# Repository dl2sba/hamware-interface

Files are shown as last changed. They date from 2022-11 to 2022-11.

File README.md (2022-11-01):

# General
A small interface board for the HAMWARE controllers AT-502, AT-515 and AT-651. This interface boards supports RS232 and CI-V communications and can be directly mounted into the controller chassis.

It is supported by my alternative HAMWARE firmware https://dl2sba.com/index.php/funk/hamware.
Some images can be found in the **images** folder.

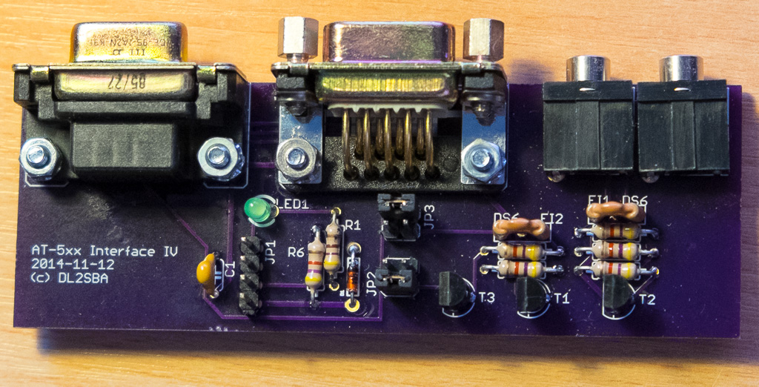
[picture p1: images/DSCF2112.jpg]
Board top

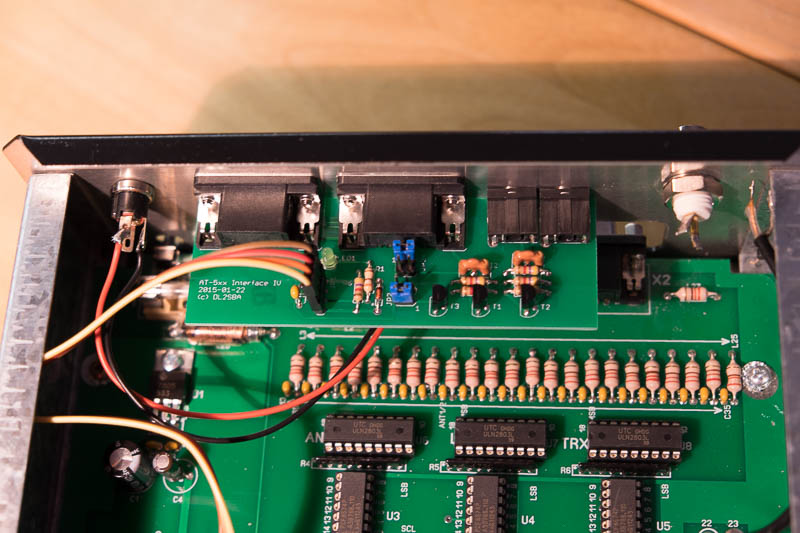
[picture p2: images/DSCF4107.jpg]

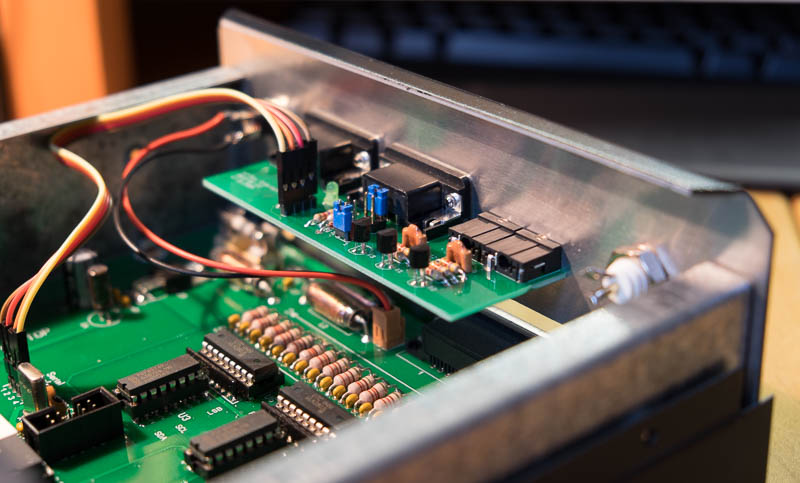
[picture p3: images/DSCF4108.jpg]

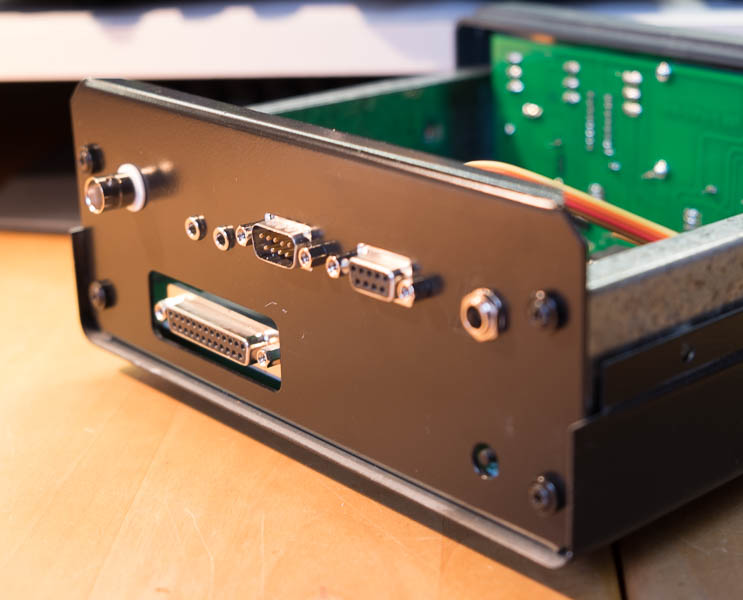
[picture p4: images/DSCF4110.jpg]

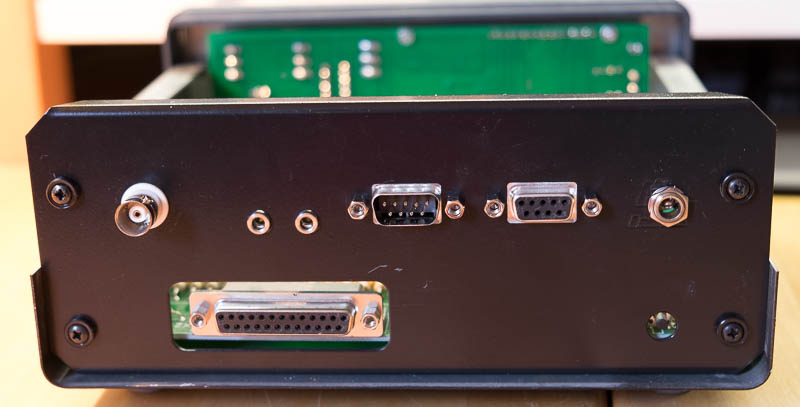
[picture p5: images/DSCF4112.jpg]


# Manual
A detailled manual can be found in **HamwareInterface_EN.pdf**

# Backpanel 
A drawing for the backpanel cutouts can be found in **Backplane.dxf**. Please verify that the cutouts matches you board / components.

# PCB production files
All relevant files can be found in the **production files** files folder. ZIP the complete folder and upload it on the webpage of one of the main PCB manufacturer.

Please verify with your PCB manufacturer that the boards satisfy your requirements.

# Parts
A public parts list for **10** boards can be found at REICHELT **https://www.reichelt.de/my/1027630**
Please adjust the part count to your requirements!

# License
The files provided here under this license **https://creativecommons.org/licenses/by-nc-nd/4.0/**
(C) Dietmar Krause, DL2SBA 2022

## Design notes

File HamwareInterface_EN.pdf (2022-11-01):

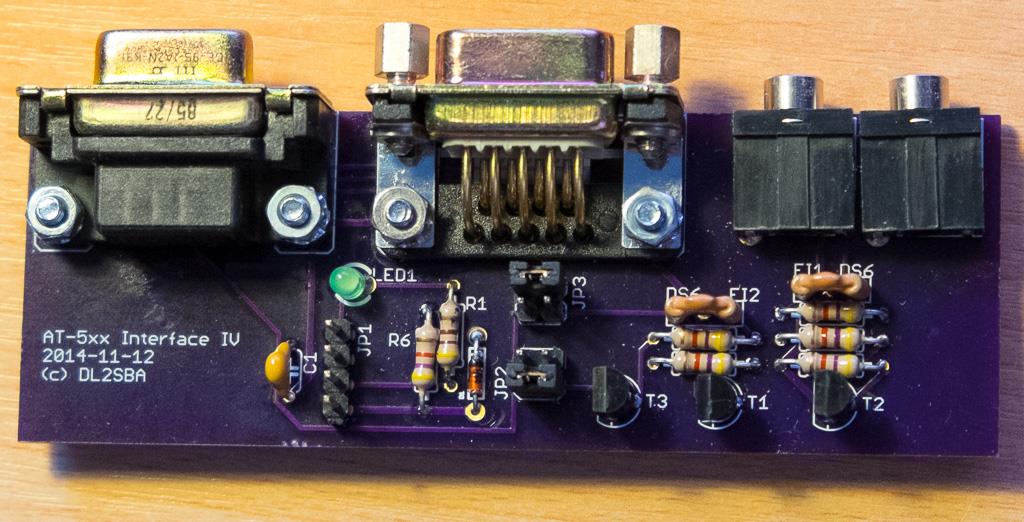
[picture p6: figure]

# Serial transceiver interface for hamware tuners

Dietmar Krause

DL2SBA

Hindenburgstraße 29

D-70794 Filderstadt

http://creativecommons.org/licenses/by-nc-nd/3.0 | Saturday, 10. February 2018

Serial transceiver interface for hamware tuners – PCB version 2015-01-22

© Dietmar Krause, DL2SBA 2018 | 2 / 9

### Content

### Change history

Version | Date | Who | Changes
1.0 | 30. December 2014 DL2SBA | Initial version
1.1 | 14. April 2017 | DL2SBA | Updated
1.2 | 4. February 2018 | DL2SBA | Updated
1.3 | 10. February 2018 | DL2SBA | Added images for new PCB layout

Remark: Any changes that you make on the control unit of the AT-XXX, is at your own risk. Please note, in any case, the general guidelines for handling sensitive electronic equipment and components.

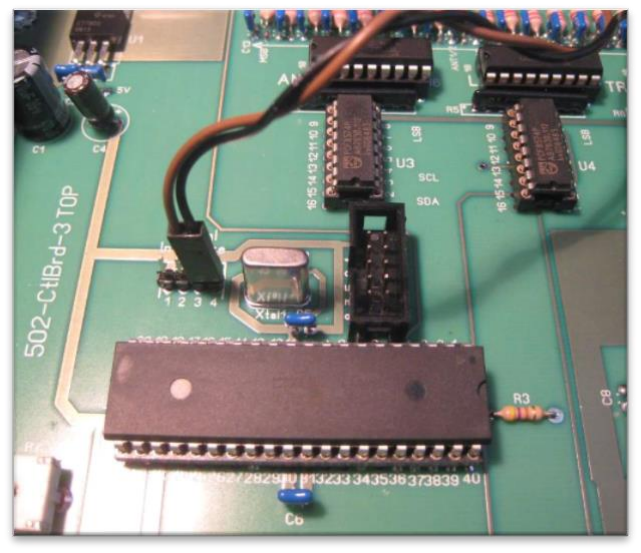
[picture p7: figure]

© Dietmar Krause, DL2SBA 2018 | 3 / 9

### Introduction

The original firmware for the HAMWARE AT-xxx tuner has a build in feature, which the frequency of a transmitter measures and according to the frequency, the correct memory channel is selected.

This feature works relatively well in CW mode, in SSB mode it’s more or less useless. Using this feature in QRP modes did not work.

I have developed a new firmware for the AT-502/AT-515 and AT-615U controllers, which takes advantage of the computer interface of the transceiver to select the matching memory.

For this firmware, you can also get a PCB for a simple computer interface. You can integrate this PCB in the AT-XXX controller boxes.

This interface is designed to communicate with transceivers either using an RS232/V.24¹
interface or
using the ICOM CI-V

2
serial interface.

Note: It is not designed for other communication types like USB, LAN, …

### Usage

Connect a 4-pin wire between JP1 on the interface board to the 4-pin connector on the controller board.

Ensure, that PIN1 of JP1 is connected to PIN1 on the controller board etc.

Place a jumper on JP2 whether a RS232 connection or a CI-V connection is needed. For location of JP2 see Figure 4 - PCB layout on page 8.

Place a jumper on JP3 whether the RS232 cable is wired as DTE or DCE. If you don’t know, simply give it a try. For location of JP3 see Figure 4 - PCB layout on page 8.

1 https://en.wikipedia.org/wiki/RS-232
2 http://www.icomamerica.com/en/support/kb/article.aspx?ArticleNumber=63AE624429

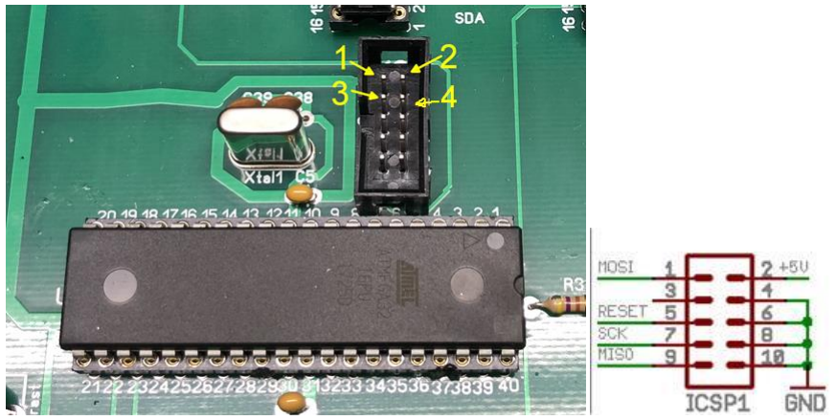
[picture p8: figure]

© Dietmar Krause, DL2SBA 2018 | 4 / 9

### Different board revisions

Some newer hardware revisions of the ATXXX control board do not have any more solder pads for the 4pin header available – I assume the manufacturer wants to reduce the copper on the board?!

### Solution 1

For this type of board, three wires must be soldered directly to the board and connected to the interface board.

Signal | Pin of JP1 on interface board | Pin on ATMEGA controller chip on AT502 board
VCC (+5VDC) | 1 | 10
RXD | 3 | 14
GND | 4 | 11
Note: | Before soldering, remove the ATMEGA controller chip from the control board of the AT502
to avoid damages to the chip

### Solution 2

For this solution, you must solder only one wire to the board. From PIN14 of the microcontroller to PIN3 on the ISP Connector.

Figure 1 - Layout and PIN numbering of the ISP connector

Now connect the jumper wires like this:

Signal | Pin of JP1 on interface board | Pin on ISP connector on AT502 board
VCC (+5VDC) | 1 | 2
RXD | 3 | 3
GND | 4 | 4
Note: | Before soldering, remove the ATMEGA controller chip from the control board of the AT502
to avoid damages to the chip

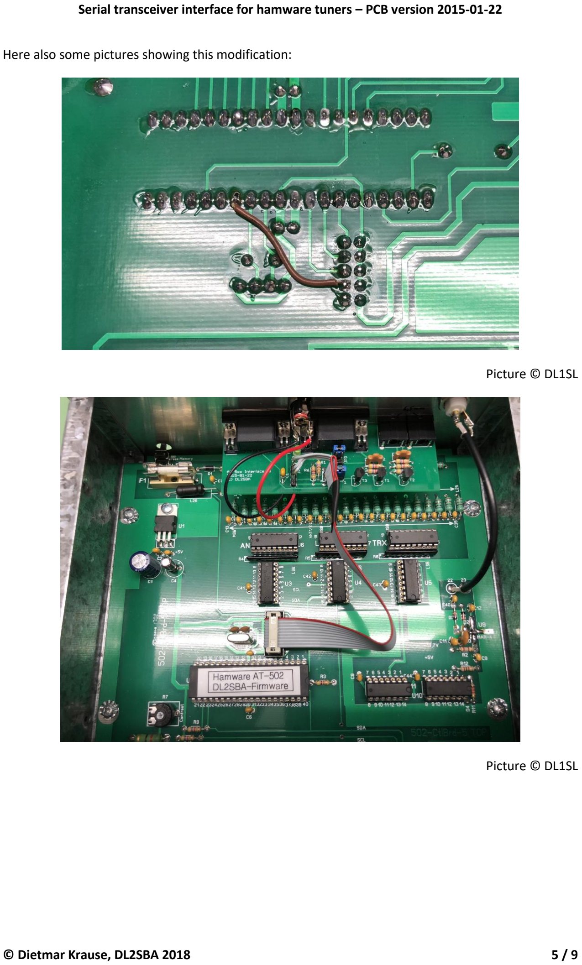
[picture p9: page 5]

© Dietmar Krause, DL2SBA 2018 | 5 / 9

Here also some pictures showing this modification:

Picture © DL1SL

Picture © DL1SL

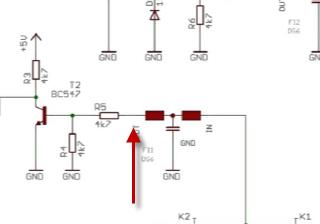
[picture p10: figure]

© Dietmar Krause, DL2SBA 2018 | 6 / 9

### CI-V problems

If you’ve configured your transceiver and the interface board correctly but the LED1 is not flickering, it may be necessary to add an additional 1KOhm pullup resistor between R5 and +5V on the interface board.

Figure 2 – Pullup resistor for CI-V bus

This usually has to be done, when the interface is the only device connected to the CI-V port of the transceiver. If there is already another (computer-) interface is connected to the transceiver, this pullup should not be necessary.

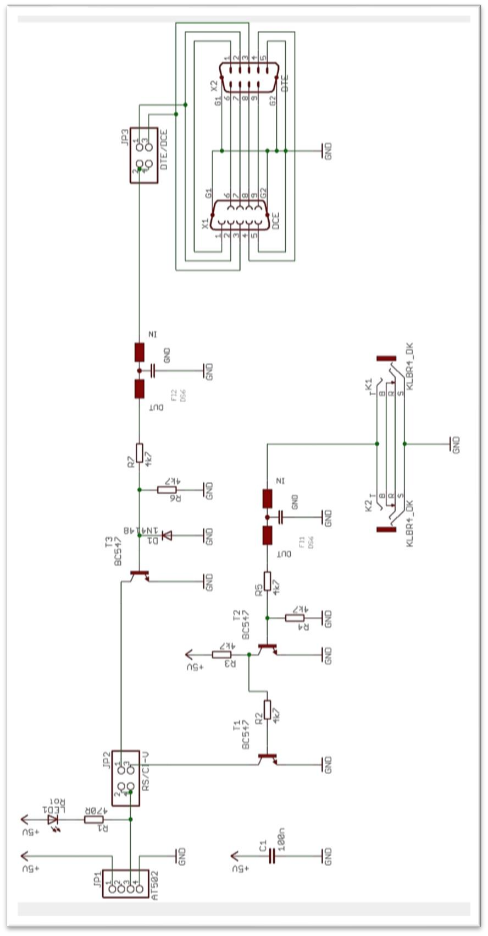
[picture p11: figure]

© Dietmar Krause, DL2SBA 2018 | 7 / 9

### Circuit diagram

Figure 3 - Circuit diagram

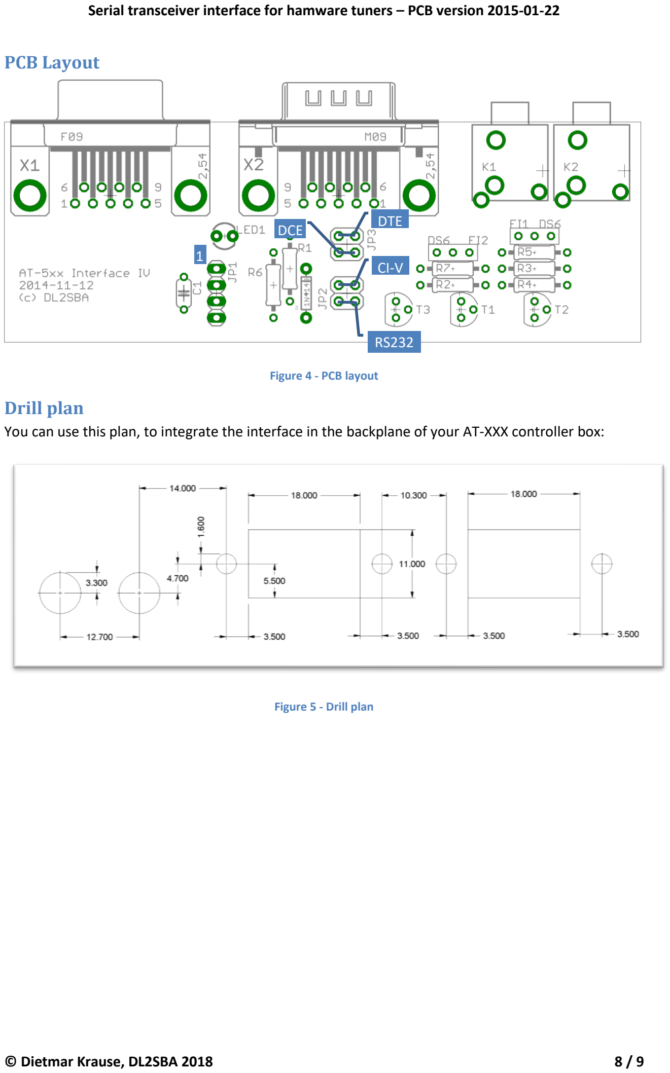
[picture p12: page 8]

© Dietmar Krause, DL2SBA 2018 | 8 / 9

### PCB Layout

Figure 4 - PCB layout

### Drill plan

You can use this plan, to integrate the interface in the backplane of your AT-XXX controller box:

Figure 5 - Drill plan

RS232

CI-V

1

DTE DCE

© Dietmar Krause, DL2SBA 2018 | 9 / 9

### Parts list

P art | Value | Des c ription
C1 | 100n | C apacitor
D1 | 1N4148 | D iode
F I1 | D S 6 | R F filter
F I2 | D S 6 | R F filter
J P 1 | AT 502 | P in header 1X4
J P 2 | R S /C I-V | P in header 2X2
J P 3 | D T E /D C E | P in header 2X2
K1 | K L B R 4_D K | L umberg 3.5mm s tereo phone jack
K2 | K L B R 4_D K | L umberg 3.5mm s tereo phone jack
L E D 1 | R ot | 3mm led
R1 | 470R | R es is tor
R2 | 4k7 | R es is tor
R3 | 4k7 | R es is tor
R4 | 4k7 | R es is tor
R5 | 4k7 | R es is tor
R6 | 4k7 | R es is tor
R7 | 4k7 | R es is tor
T1 | B C 547 | T rans is tor
T2 | B C 547 | T rans is tor
T3 | B C 547 | T rans is tor
X1 | D C E | D B 9S UB F emale
X2 | D T E | D B 9S UB Male
P C B | P C B | P C B Vers ion 2014-11-12

Table 1 - Parts List

### Links

http://hamware.de | Manufacturer of the tuner
http://www.dl2sba.de | Manufacturer of the new firmware for the hamware tuners

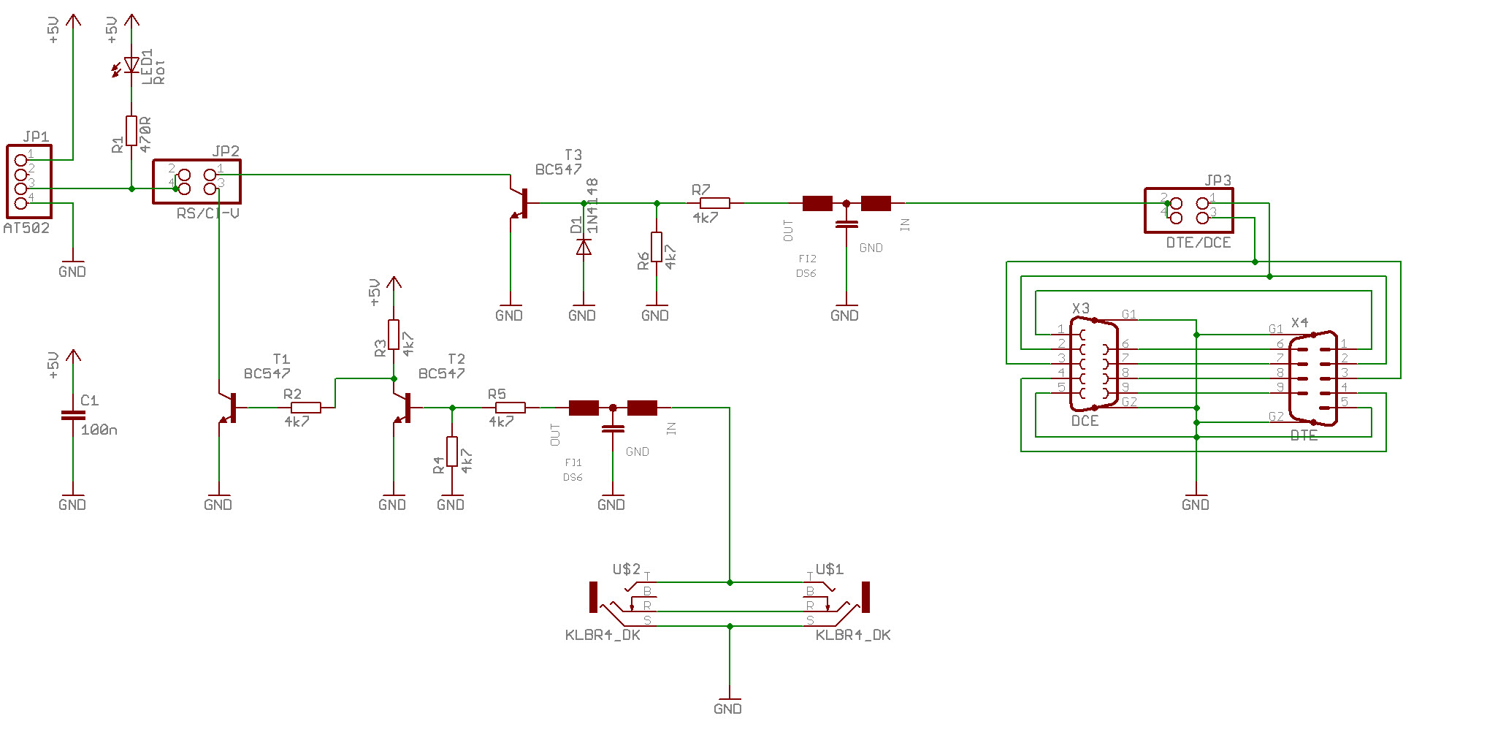
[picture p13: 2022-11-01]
images/IF_CIRC.jpg

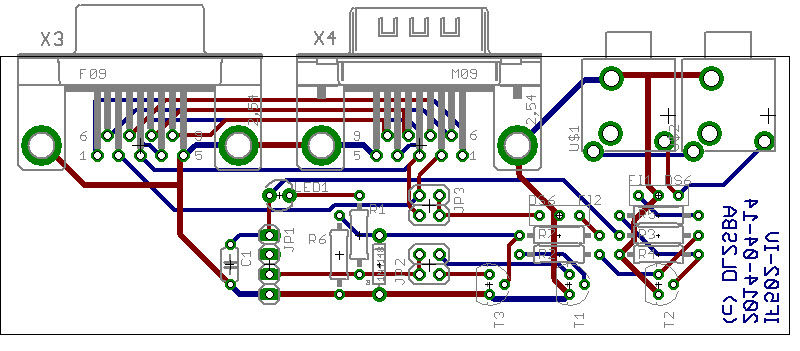
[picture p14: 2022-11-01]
images/IF_LAY.jpg

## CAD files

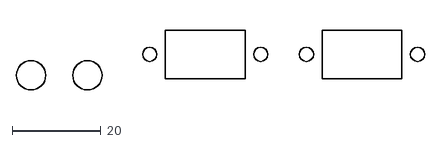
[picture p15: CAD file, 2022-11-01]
Backplane.dxf
91.9 x 13.5
